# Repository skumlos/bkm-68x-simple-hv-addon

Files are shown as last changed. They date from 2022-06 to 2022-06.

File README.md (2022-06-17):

BKM-68X Alternative HV Sync Add-on

This small experimental board is meant to wired to the BKM-68X Alternative Rev. E1 (or earlier that has the HD_SD_X pad) to
provide a discrete VSYNC input, and thus support RGBHV signals. The FPGA needs to be programmed with at least version 1.3 of
the firmware, and using the Quartus project where the HD_SD_X pin has been reconfigured to discrete VSYNC in.

Since the board cannot easily be soldered and fastened to the BKM-68X Alternative board, it is meant to be fastened to the
bracket, so the bracket needs to be replaced with bracket that has the appropriate hole. The Keystone 7794 is not mandatory
but will provide further support of the board if used. The BNC jack needs to be rather low profile to avoid the THT pins
touching the board, seemingly the Molex 73171-0702 is appropriate.

The board needs 5 connections, two going to the "analog part" of the board, that being the 5V and GNDA, two going to the
"digital part" being 3.3V and GND. FPGA SYNC pad then needs to be wired to the HD_SD_X pad. As the VSYNC signal is rather
low speed (so 50/60Hz) routing/wiring shouldn't be extremely important, but try to keep the wire close to the "digital"
ground part. C103 is as such optional, if chosen it should most likely be in the 1nF range. It is there to help the return
path of the signals.

Use at your own risk, very untested :)

(2022) Martin Hejnfelt (martin@hejnfelt.com)
www.immerhax.com

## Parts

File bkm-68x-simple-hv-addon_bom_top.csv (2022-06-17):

Comment | Designator | Footprint | LCSC Part #
Conn_Coaxial | J101
10K | R101 | 0805 | C84376
1K | R102 | 0805 | C95781
75R | R103 | 0805 | C141697
MMBT3904 | Q101 | SOT-23(SOT-23-3) | C94514
68R | R201 | 0805 | C137498
100uF | C101 C201 | SMD,6.3x5.5mm | C111600
100nF | C102 C202 | 0805 | C1711
NM | C103 | 0805
74LVC1G34 | U201 | SOT-23-5 | C840096

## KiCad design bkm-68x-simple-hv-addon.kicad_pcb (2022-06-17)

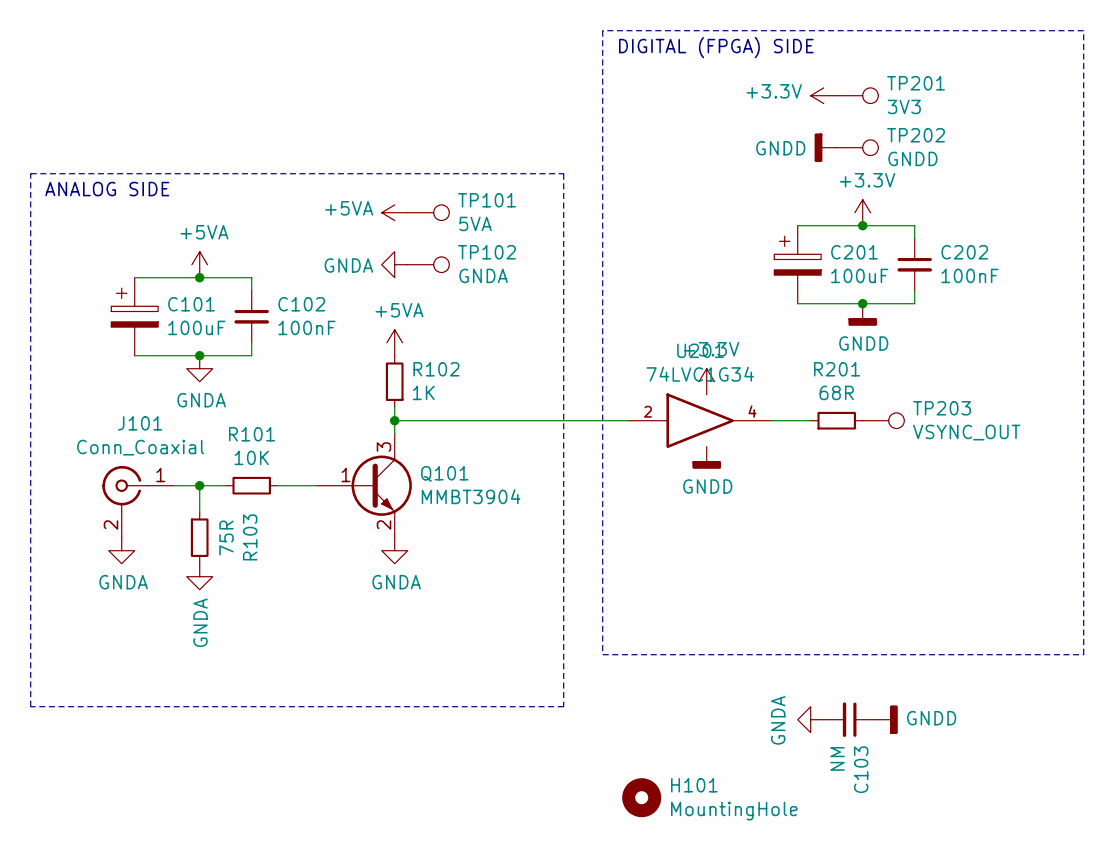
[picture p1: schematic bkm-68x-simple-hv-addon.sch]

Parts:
C101, C201: 100uF; CP_Elec_6.3x5.4; JLC SMD,6.3x5.5mm
C102, C202: 100nF; C_0805_2012Metric_Pad1.18x1.45mm_HandSolder; JLC 0805
C103: NM; C_0805_2012Metric_Pad1.18x1.45mm_HandSolder; JLC 0805
H101: MountingHole; 7794-X
J101: Conn_Coaxial; BNC-THT
Q101: MMBT3904; SOT-23; JLC SOT-23(SOT-23-3)
R101: 10K; R_0805_2012Metric_Pad1.20x1.40mm_HandSolder; JLC 0805
R102: 1K; R_0805_2012Metric_Pad1.20x1.40mm_HandSolder; JLC 0805
R103: 75R; R_0805_2012Metric_Pad1.20x1.40mm_HandSolder; JLC 0805
R201: 68R; R_0805_2012Metric_Pad1.20x1.40mm_HandSolder; JLC 0805
TP101: 5VA; TestPoint_Pad_2.5x2.5mm
TP102: GNDA; TestPoint_Pad_2.5x2.5mm
TP201: 3V3; TestPoint_Pad_2.5x2.5mm
TP202: GNDD; TestPoint_Pad_2.5x2.5mm
TP203: VSYNC_OUT; TestPoint_Pad_2.5x2.5mm
U201: 74LVC1G34; SOT-23-5_HandSoldering; JLC SOT-23-5

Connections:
+3V3: C201.1, C202.1, TP201.1, U201.5 (VCC)
+5VA: C101.1, C102.1, R102.2, TP101.1
GND: C103.1, C201.2, C202.2, TP202.1, U201.3 (GND)
GNDA: C101.2, C102.2, C103.2, J101.2 (Ext), Q101.2 (E), R103.2, TP102.1
unnamed: J101.1 (In), R101.2, R103.1
unnamed: Q101.1 (B), R101.1
unnamed: Q101.3 (C), R102.1, U201.2
unnamed: R201.1, U201.4
unnamed: R201.2, TP203.1

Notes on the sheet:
ANALOG SIDE
DIGITAL (FPGA) SIDE

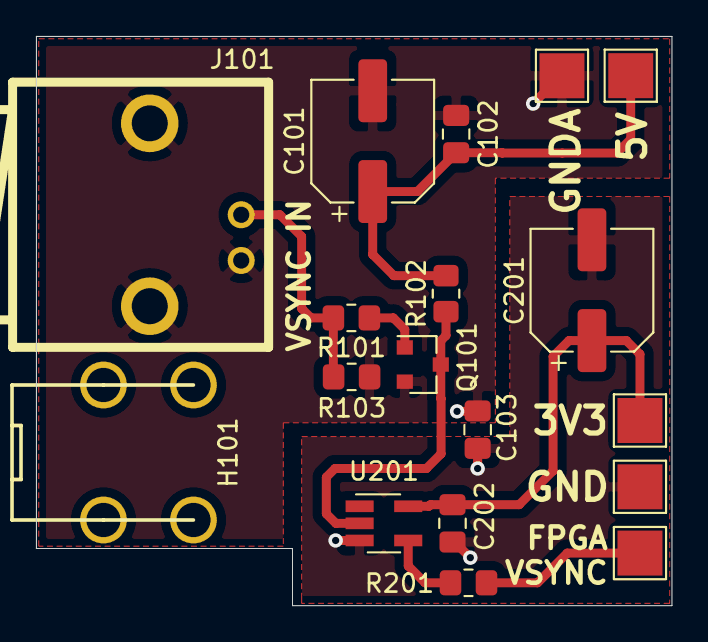
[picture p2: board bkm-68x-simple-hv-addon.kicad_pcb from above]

Board: 2 copper layers, 35.3 x 31.6 mm, 18 parts (0 on the bottom side), 9 nets.
